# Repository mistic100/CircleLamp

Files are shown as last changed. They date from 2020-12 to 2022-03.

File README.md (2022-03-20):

# CircleLamp

A circular lamp using LED strip inspired by [this design by minchang kwon](https://www.thingiverse.com/thing:4659384).

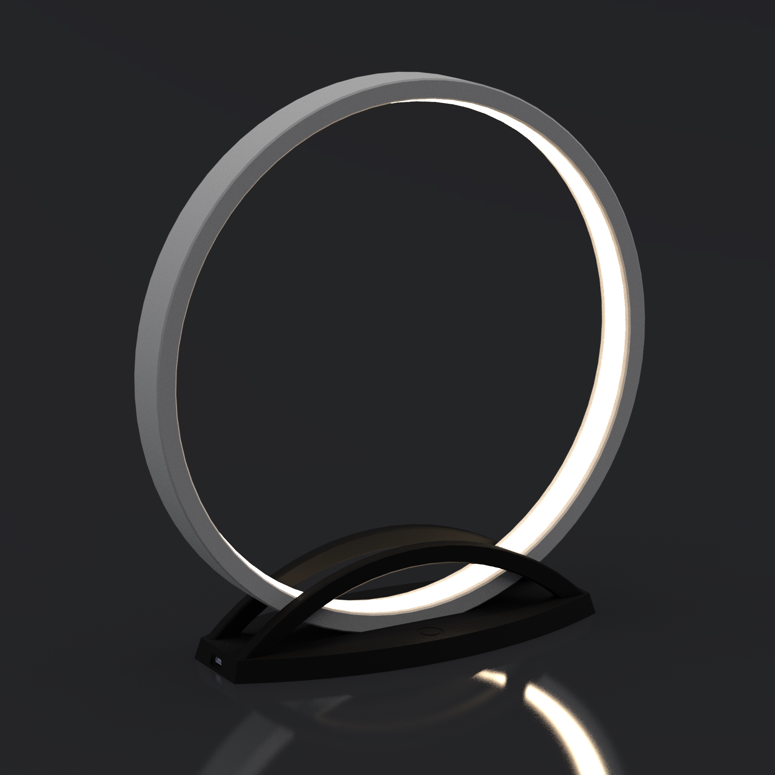
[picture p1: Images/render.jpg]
render


[Photos on my website](https://galerie.strangeplanet.fr/index.php?/category/203)

There are two versions of the base :

- one for a adressable LED strip + Arduino Nano
- one for a simple 12V strip + dimmer

## Parts list

### 3D printed parts

- 3x arc
- 1x arc-wire
- 1x support or support2
- 2x support-arc

### Electronics

- Adressable version
  - 1 meter SK6812 WWA LED strip (60 LEDS/m)
  - 1x Arduino Nano
  - 1x TTTP223 touch button
  - 1x Micro-USB breakout
  - 1x 2A USB wall adapter + USB cable
- Simple version
  - 1 meter natural white 12v LED strip ([COB strip](https://aliexpress.com/item/4000145232270.html) prefered)
  - 1x [capacitive dimmer](https://aliexpress.com/item/1005002395129687.html)
  - 1x 5.5mm DC Jack
  - 1x 2A 12V wall adapter

### Hardware

- 1 meter T2016 LED Strip tube (cut the white part with an utility knife)

## Controls (adressable version only)

**Single touch**  
On/Off

**Long touch (< 1s)**  
Next mode

- Mode 0 : full brightness (default)
- Mode 1 : static configurable temperature
- Mode 2 : "rainbow" of temperatures
- Mode 3 : candle animation

**Long touch (> 1s)**  
Increase/decrease brightness

**Double touch**  
Enter config mode. The ring will blink three times, double touch again to exit config, the ring will blink twice.

- Mode 0 : not configurable
- Mode 1 : long touch to change the temperature
- Mode 2 : not configurable
- Mode 3 : not configurable

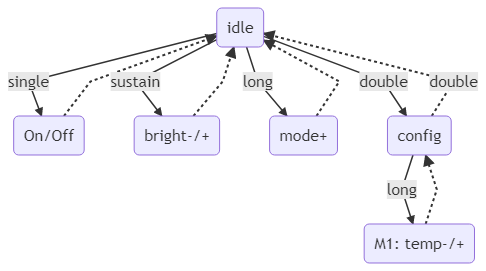
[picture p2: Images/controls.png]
controls


<details> 
  <summary>Mermaid</summary>
  
```mermaid
graph TD
  A(idle)
  B(On/Off)
  C(bright-/+)
  D(mode+)
  E(config)
  F(M1: temp-/+)
  A -->|single| B
  B -.-> A
  A -->|sustain| C
  C -.-> A
  A -->|long| D
  D -.-> A
  A -->|double| E
  E -.->|double| A
  E -->|long| F
  F -.-> E
```

</details>

## License

The SolidWorks files and Arduino code are distributed under the Creative Commons 3.0 BY-SA license.

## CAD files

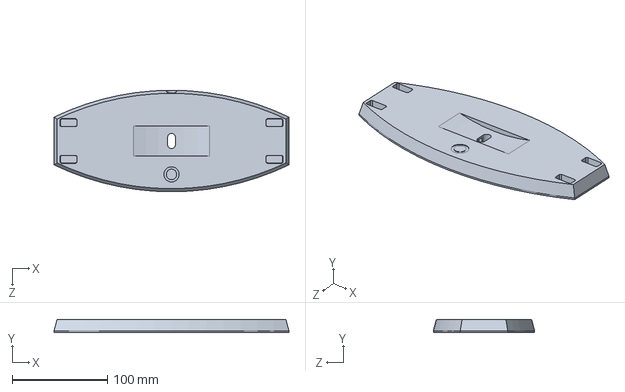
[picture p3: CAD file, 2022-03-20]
SolidWorks/support2.SLDPRT
246.4 x 13.6 x 106.4 mm

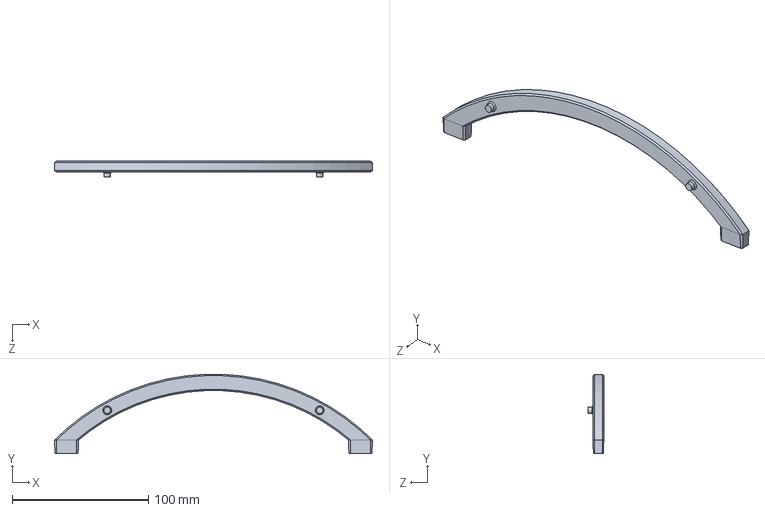
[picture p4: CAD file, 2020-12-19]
SolidWorks/support-arc.SLDPRT
233.6 x 58.2 x 11.5 mm

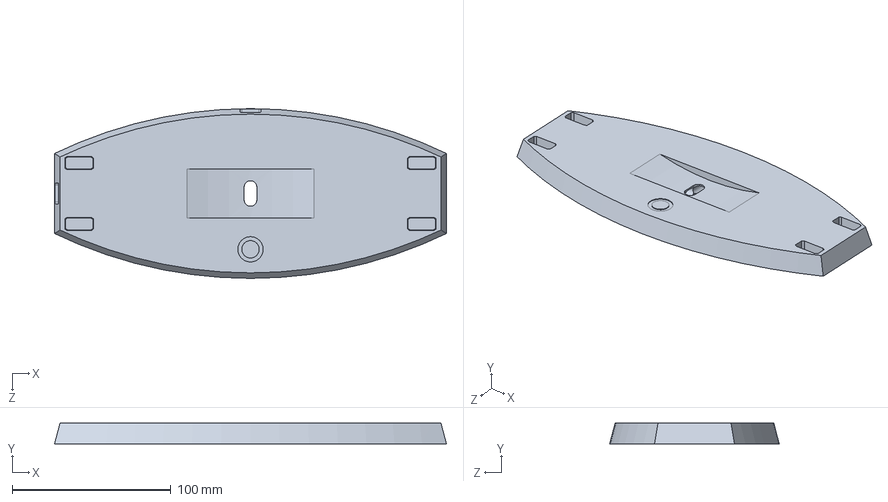
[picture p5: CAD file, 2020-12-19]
SolidWorks/support.SLDPRT
247.0 x 13.0 x 107.0 mm

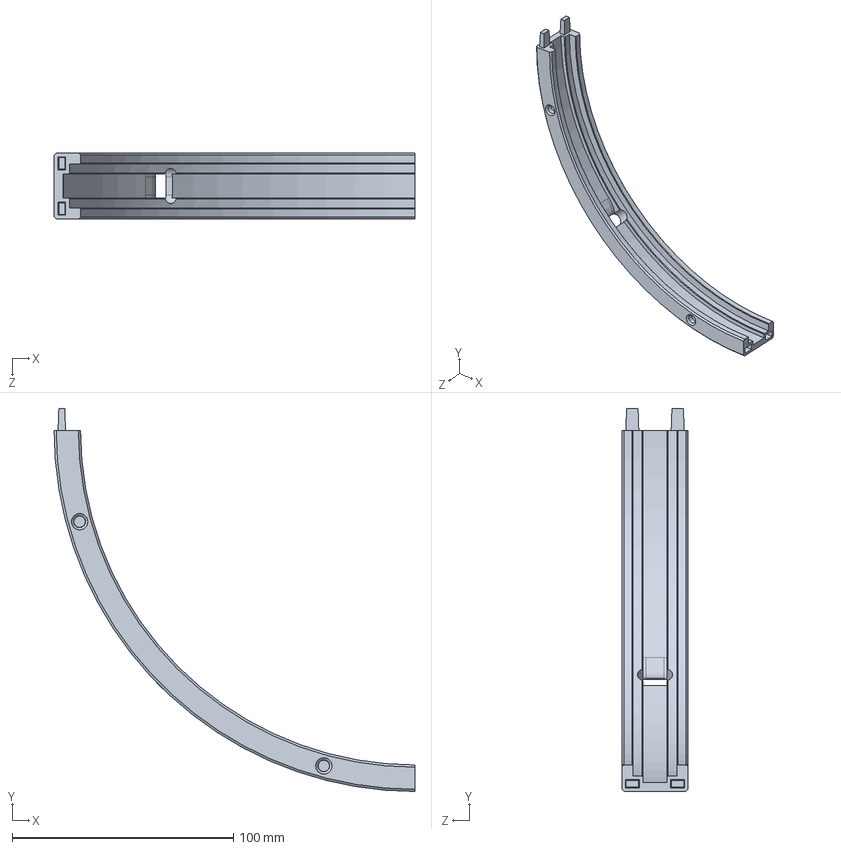
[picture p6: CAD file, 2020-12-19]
SolidWorks/arc-wire.SLDPRT
163.2 x 173.2 x 30.0 mm

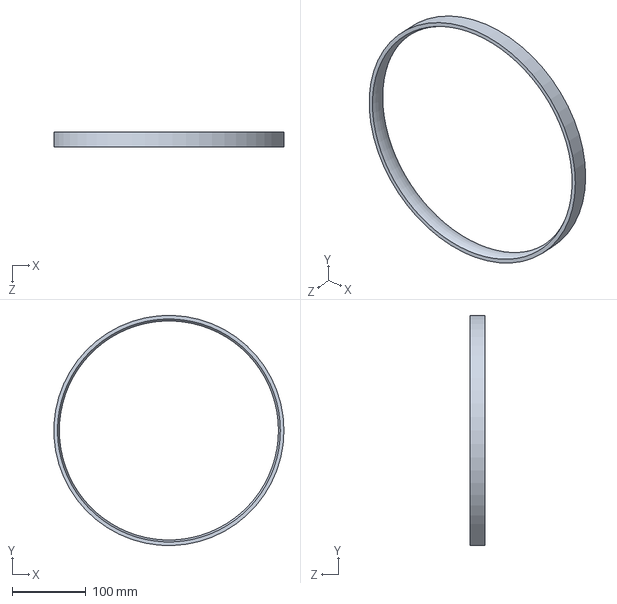
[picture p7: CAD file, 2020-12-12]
SolidWorks/difuser.SLDPRT
312.0 x 312.2 x 20.0 mm

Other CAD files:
SolidWorks/arc.SLDPRT
STL/arc-wire.STL
STL/arc.STL
STL/support-arc.STL
STL/support.STL
STL/support2.STL

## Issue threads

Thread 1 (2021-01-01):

Lack of diffuser in stl format

mannymiller2012, 2021-01-01:
Hey great looking lamp.  I have converted the diffuser from the dreamworks folder but this exceeds the print space even on my cr10. can the diffuser be split into 4 pieces and shared in stl format.

mistic100, 2021-01-02:
The diffuser is not meant to be printed, it is a silicone diffuser from AliExpress. It needs to be redesigned of you want to print it.

Closed 2021-01-02.

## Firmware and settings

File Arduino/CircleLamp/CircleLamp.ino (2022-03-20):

#include "FastLED.h"

#define LED_PIN 4
#define NUM_LEDS 60
#define LED_TYPE WS2812
#define COLOR_ORDER BRG
// R = Amber
// G = Warm White
// B = Cold White

#define BUTTON_PIN A0
#define BUTTON_THRES 500
#define BUTTON_DELAY 300
#define BUTTON_SUSTAIN_DELAY 1000
#define BUTTON_SUSTAIN_INTERVAL 40

#define TEMP_MAX 171

#define BTN_IDLE 0
#define BTN_SINGLE 1
#define BTN_SUSTAIN 2
#define BTN_RELEASE 3

#define MODE_FULL 0
#define MODE_STATIC 1
#define MODE_RAINBOW 2
#define MODE_CANDLE 3
#define MODE_MAX_ MODE_CANDLE

unsigned long btnTime = 0;
uint8_t btnState = BTN_IDLE;
bool btnDouble = false;

CRGB leds[NUM_LEDS];
uint8_t mode = MODE_FULL;
bool on = true;
bool inConfig = false;
bool configDirection = true;
uint8_t brightness = 255;
uint8_t temperature = 128;

void setup() {
  Serial.begin(9600);
  FastLED.addLeds<LED_TYPE, LED_PIN, COLOR_ORDER>(leds, NUM_LEDS);
}

void loop() {
  manageButton();

  if (!on) {
    modeOff();
  }
  else {
    switch (mode) {
      case MODE_FULL:
        modeFull();
        break;
      
      case MODE_STATIC:
        modeStatic();
        break;

      case MODE_RAINBOW:
        modeRainbow();
        break;

      case MODE_CANDLE:
        modeCandle();
        break;
    }
  }

  FastLED.setBrightness(brightness);
  FastLED.show();
  
  FastLED.delay(20);
}

void modeOff() {
  fill_solid(leds, NUM_LEDS, CRGB::Black);
}

void modeFull() {
  fill_solid(leds, NUM_LEDS, CRGB::White);
}

void modeStatic() {
  CRGB color = ColorFromPalette(RainbowColors_p, temperature);
  fill_solid(leds, NUM_LEDS, color);
}

void modeRainbow() {
  for (uint8_t i = 0; i < NUM_LEDS; i++) {
    uint8_t index = 255.0 * i / (NUM_LEDS - 1);
    leds[i] = ColorFromPalette(RainbowColors_p, index);
  }
}

#define HALF_LEDS NUM_LEDS / 2
void modeCandle() {
  // Array of temperature readings at each simulation cell
  static byte heat[HALF_LEDS];

  static uint8_t IGNIT = 8;
  static uint8_t COOLING = 40;
  static uint8_t SPARKING = 120;

  // Step 1.  Cool down every cell a little
  for (int i = 0; i < HALF_LEDS; i++) {
    heat[i] = qsub8(heat[i], random8(0, ((COOLING * 10) / HALF_LEDS) + 2));
  }
  
  // Step 2.  Heat from each cell drifts 'up' and diffuses a little
  for (int k = HALF_LEDS - 1; k >= 2; k--) {
    heat[k] = (heat[k - 1] + heat[k - 1] + heat[k - 2] + heat[k - 3]) / 5;
  }
  
  // Step 3.  Randomly ignite new 'sparks' of heat near the bottom
  if (random8() < SPARKING) {
    int y = random8(IGNIT);
    heat[y] = qadd8(heat[y], random8(160-y,255-y));
  }

  // Step 4.  Map from heat cells to LED colors
  for (int j = 0; j < HALF_LEDS; j++) {
    // Scale the heat value from 0-255 down to 0-240
    // for best results with color palettes.
    byte colorindex = scale8(heat[j], 240);
    CRGB color = ColorFromPalette(HeatColors_p, colorindex);
    
    leds[j] = color;
    leds[NUM_LEDS - 1 - j] = color;
  }

  FastLED.delay(10);
}

void blink(uint8_t nb) {
  for (uint8_t i = 0; i < nb; i++) {
    fill_solid(leds, NUM_LEDS, CRGB::Black);
    FastLED.delay(200);
    fill_solid(leds, NUM_LEDS, CRGB::Gray);
    FastLED.delay(100);
  }
}

void singlePress() {
  on = !on;
  inConfig = false;
}

void doublePress() {
  if (!on) {
    return;
  }

  configDirection = true;
  
  if (mode == MODE_STATIC) {
    if (inConfig) {
      inConfig = false;
      blink(2);
    } else {
      inConfig = true;
      blink(3);
    }
  }
}

void longPress() {
  if (!on) {
    on = true;
    return;
  }
  if (inConfig) {
    return;
  }
  
  mode++;
  if (mode > MODE_MAX_) {
    mode = 0;
  }
}

void sustain(bool isLast) {
  if (!on) {
    return;
  }

  if (isLast) {
    configDirection = !configDirection;
    return;
  }
  
  if (inConfig) {
    switch (mode) {
      case MODE_STATIC:
        if (configDirection) {
          if (temperature < TEMP_MAX) {
            temperature++;
          }
        } else {
          temperature = qsub8(temperature, 1);
        }
        break;
    }

    return;
  }
  
  if (configDirection) {
    brightness = qadd8(brightness, 5);
  } else {
    brightness = qsub8(brightness, 5);
  }
}

void manageButton() {
  if (analogRead(BUTTON_PIN) > BUTTON_THRES) {
    switch (btnState) {
      case BTN_RELEASE:
        btnDouble = true;
      case BTN_IDLE:
        btnTime = millis();
        btnState = BTN_SINGLE;
        break;
        
      case BTN_SINGLE:
        if (millis() - btnTime > BUTTON_SUSTAIN_DELAY) {
          sustain(false);
          btnTime = millis();
          btnState = BTN_SUSTAIN;
        }
        break;
        
      case BTN_SUSTAIN:
        if (millis() - btnTime > BUTTON_SUSTAIN_INTERVAL) {
          sustain(false);
          btnTime = millis();
        }
        break;
    }
    
  } else {
    switch (btnState) {
      case BTN_SINGLE:
        if (millis() - btnTime < BUTTON_DELAY) {
          btnTime = millis();
          btnState = BTN_RELEASE;
        } else {
          longPress();
          btnState = BTN_IDLE;
          btnDouble = false;
        }
        break;
        
      case BTN_SUSTAIN:
        sustain(true);
        btnState = BTN_IDLE;
        btnDouble = false;
        break;

      case BTN_RELEASE:
        if (btnDouble) {
          doublePress();
          btnState = BTN_IDLE;
          btnDouble = false;
        } else if (millis() - btnTime >= BUTTON_DELAY) {
          singlePress();
          btnState = BTN_IDLE;
          btnDouble = false;
        }
        break;
    }
  }
}

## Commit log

2020-12-12 Add render
    [difuser.SLDPRT]
2020-12-19 New locking mechanism
    [arc-wire.SLDPRT, arc-wire.STL, support-arc.SLDPRT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]
2020-12-20 Orient support STL
    [support.STL]
2022-03-20 Add simple base
    [support2.SLDPRT, support2.STL]
